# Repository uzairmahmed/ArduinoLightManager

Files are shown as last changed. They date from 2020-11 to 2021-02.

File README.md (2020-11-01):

# Google Home Lightstrip Controller
**Make your own smart LED Strips using Google Actions, Firebase Functions, Arduino, and the ESP8266 WiFi chip.**

*This guide is based off [shivasiddarth's](https://github.com/shivasiddharth) [YouTube Tutorial](https://www.youtube.com/watch?v=e1C5WIfZ89s&t=1096s)*

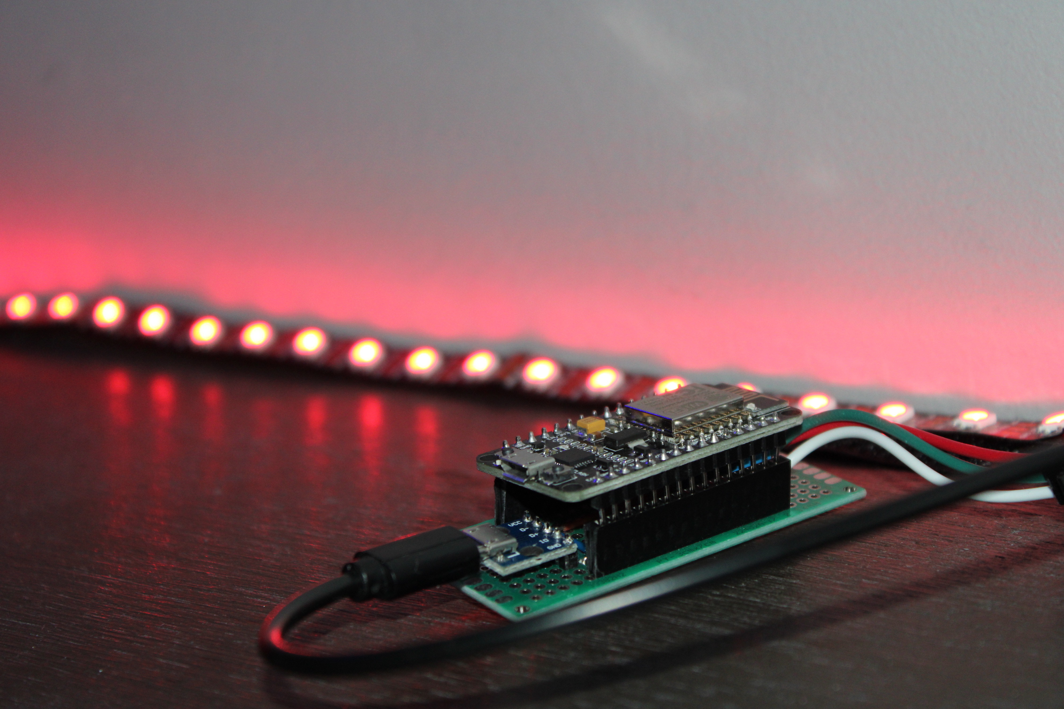
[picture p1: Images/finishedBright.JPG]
finishedController

---

## Google Actions Setup

1. Go to [Google Actions Console](console.actions.google.com)
2. Create a Project
3. Select `Smart Home`
4. Choose a name for the Action
5. Go to `Actions` and add the following fullfillment URL
    - `https://us-central1-PROJECT_ID.cloudfunctions.net/smarthome`
6. Go to `Account Linking` and add a Client ID and Secret
    - ID: `ABC123`
    - Secret `DEF456`
    - `https://us-central1-PROJECT_ID.cloudfunctions.net/fakeauth`
    - `https://us-central1-PROJECT_ID.cloudfunctions.net/faketoken`
7. Click Next
8. Go to Cloud Console and enable the `HomeGraph API` in `APIs and Services`
9. Add Credentials
    - Select `Service Account` and add the `Service Account Token Creator` role.
    - Create a JSON Key

---

## Firebase Setup

### Firebase Directory Setup

1. Clone this repository
2. Save the JSON key file from the previous step to `./Firebase/arduino-nodemcu-control/functions/smart-home-key.json`
3. Download [NodeJS](https://nodejs.org/en/)
4. Open a Powershell Terminal with administrator privileges
5. `cd` into `Firebase\arduino-nodemcu-control\functions`
6. `Set-ExecutionPolicy RemoteSigned` to enable scripts
7. `npm install -g firebase-tools` to install firebase
8. `firebase login`
9. `firebase use PROJECT_ID`
10. `npm i`
11. Go to [Firebase](console.firebase.google.com)
12. Click `Database > Create Database > Enable`, and copy the URL given
13. Click `Settings > Users and permissions > Service Accounts > Database secrets`  and copy the secret given

### Smart Devices Setup

1. For each device you intend to use, add an entry to the devices array inside `Firebase\arduino-nodemcu-control\functions\devices.json`
    - Use the template given in `Firebase\arduino-nodemcu-control\functions\device_template.json` for your entry
2. Customize your device further by referencing to the [Google Smarthome Docs](https://developers.google.com/assistant/smarthome/guides)

### Firebase Deployment

1. In a terminal, `cd` into `Firebase\arduino-nodemcu-control\functions`
2. `firebase deploy`
3. Go to the link specified.
4. Click `Database > Create Database > Enable`, and note down the URL given
5. Click `Realtime Database`
6. Click `Settings > Users and permissions > Service Accounts > Database secrets` and note down the secret given
7. Save your URL and Secret in a file, **you will need it later**.

---

## Hardware Setup

soldering

**Note:** The steps outlined above work for any type of device/hardware (lights, fans, motors, etc). The steps below are specifically to control LightStrips with Cloud Functions

### Circuit Building

#### **Components Needed**

- **1x** NodeMCU ESP8266 Development Board
- **1x** WS2812 LED Strip
- **1x** MicroUSB PinBoard (Female)
- **1x** 3-Pin Screw Terminal
- **2x** 15-Pin Headers
- **1x** 5-Pin Headers
- **5x** Jumper Cables
- **1x** 10x24-Hole Perfboard
- **1x** Micro USB Cable
- **1x** USB Power Supply

#### **Power Requirements**

The ESP8266 board operates at 3.3V, however the WS2812 operates at 5V. Additionally, the maximum current that can be drawn from each GPIO pin is 12mA. For this reason we need to power the board independently from the lightstrip, and with a larger power supply.

To choose an adequate power supply, we need to calculate the maximum current drawn from the arduino and the lights.

ESP8266 Board Max Current Draw: 400mA

WS2812 Strip Max Current Draw (all pixels are bright white): 3.6A

- Each LED draws a maximum of 60mA (Red, Green, Blue)
- 60 LED strip = 3.6 Amps required.

Therefore we need a 5V / 4A Power Supply.

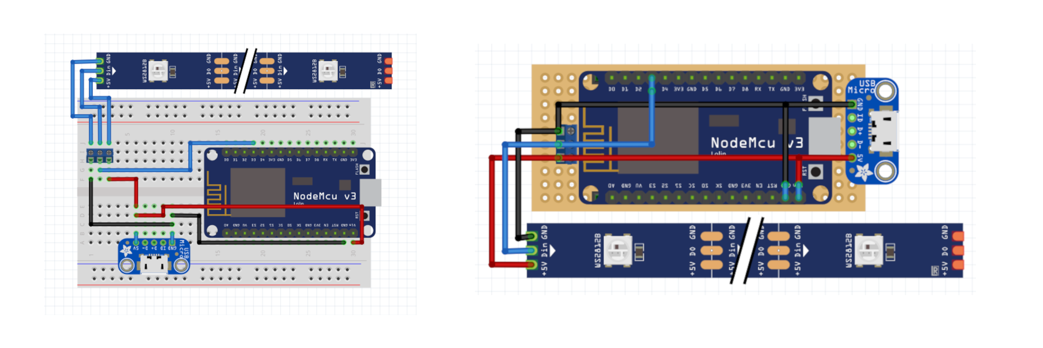
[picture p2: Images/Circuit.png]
Circuit


#### **Breadboard Testing**

1. Open `Wiring\Breadboard_Wiring.png`, and create the circuit shown.
2. To test the circuit, open `Arduino\OfflineLightManager\OfflineLightManager.ino` in Arduino.
3. If you have not already, setup your ESP8266 Board to work with Arduino IDE, Steps shown below in `Setup Arduino/NodeMCU Setup with Arduino IDE`.
4. Go to `Tools > Library Manager` and get
    - `FastLED` by `Daniel Garcia`
5. Connect the circuit to your computer using the microUSB port **on the ESP8266 board**
Click Upload
6. Confirm that the light strip turns on.
7. Reconnect the ciruit to your computer, but this time, use the microUSB port **on the external pinboard**
8. Confirm that the light strip turns on (but brighter).

#### **Perfboard Testing**

1. Open `Wiring\Perfboard_Wiring.png`, and solder the circuit shown.
2. Repeat steps 5-8 from the previous section to confirm your circuit board works.

### Arduino Setup

#### Configure NodeMCU with Arduino IDE

1. Open Arduino
2. Go to `File > Preferences`, under `Additional Boards Manager URLS` paste the following URL: `http://arduino.esp8266.com/stable/package_esp8266com_index.json`
3. Go to `Tools > Board > Boards Manager` and get `esp8266` by ESP8266 Community
4. Go to `Tools > Board` and select `NodeMCU 1.0 (ESP-12E)`

#### Upload LightManager Code

1. Download the git repository at [FirebaseExtended/firebase-arduino](https://github.com/FirebaseExtended/firebase-arduino)
2. Open `Arduino\LightManager\LightManager.ino` in Arduino.
3. Go to `Sketch > Include Library > Add ZIP Library`
4. Go to `Tools > Library Manager` and get

    - `ArduinoJSON` **v5.13** by `Benoit Blanchon`,
    - `WiFiManager` by `Tzapu, Tablatronix`,
    - `Adafruit_Neopixel` by `Adafruit`

5. Make the following changes to the code:
    - Replace `FIREBASE_URL` with the Firebase URL **saved earlier**.
    - Replace `FIREBASE_KEY` with the Firebase Secret **saved earlier**.
    - For each device you make:
        - Edit `LED_Count` variable to match the number of LEDs in your strip.
        - Edit `STRMDEVID` variable to match the ID of the device you created in `Firebase\arduino-nodemcu-control\functions\devices.json`.

6. Verify your code
7. Upload your code
8. Connect to the WiFi Network created by your ESP8266
9. Click `Configure Wifi` and connect to your home WiFi address (2.4GHz only)

---

## Google Home Setup

### Setup

1. Open your [Google Actions](console.actions.google.com) project
2. Go to `Google Actions Console > Test`
3. Invoke a test in the simulator, you will get an error, and then the Action will activate.
4. Open the Google Home app on a mobile device.
5. Go to `'+' > Set up Device > Have something already setup? > '[Test] Device Name'`
6. Add the [Test] Devices to a room and test the lights.
7. Refer to `Debugging` Below if something isn't working correctly.
8. **Congratulations! You've made your own smart Light Strips!**

Finished

---

---

## Debugging

If your lights aren't working properly, follow these steps to find the root of the issue.

1. Click the reset button on your ESP8266 Board (**this solves most issues**)
2. Firebase Debugging
    - Go to [Firebase Console](console.firebase.google.com) and open Realtime Database.
    - Change the color of your lights and make sure the values are changing in the database. 
        - If the database is unresponsive:
            - Confirm that Google Actions is setup properly with Firebase
            - Clear the Database and try changing colors again
            - Redeploy your Firebase Functions
        - If the database changes values properly, go to `External USB Debugging`.
3. External USB Debugging
    - Disconnect your circuit from the light strip and connect it to your computer using the microUSB port **on the ESP8266 board**.
    - Change the color of your lights and check if the lights change colors properly.
        - If they change properly, your external microUSB wiring isn't properly connected.
        - If they dont change, go to `Arduino WiFi Debugging`
4. Arduino WiFi Debugging
    - With your circuit connected to your computer, open Arduino,
    - Go to `Tools > Serial Monitor`.
    - If the serial monitor is sending `Streaming Error` indefinitely, check that your WiFi works properly.
    - OR If the serial monitor is sending instructions to connect to a WiFi network connect to the WiFi Network created by your ESP8266 and reconfigure your board.
    - OR Change the color of your lights and confirm that the serial monitor sends `patch` with the function you just activated.
        - If nothing shows up, confirm that Firebase is setup properly with Arduino
        - If the right output shows up, go to `Arduino Offline Debugging`
    - If none of the above worked/applied to you, go to `Arduino Offline Debugging`
5. Arduino Offline Debugging
    - Open `Arduino\OfflineLightManager\OfflineLightManager.ino` in Arduino.
    - If you don't have it already, go to `Tools > Library Manager` and get `FastLED` by `Daniel Garcia`
    - Upload the code and make sure that the LED strip turns on.
        - If the LED strip doesn't turn on, check your wiring, and make sure there are no short circuits anywhere.
        - If the LED strip does turn on properly, **something is wrong with your Google Actions / Firebase / LightController.ino setup**

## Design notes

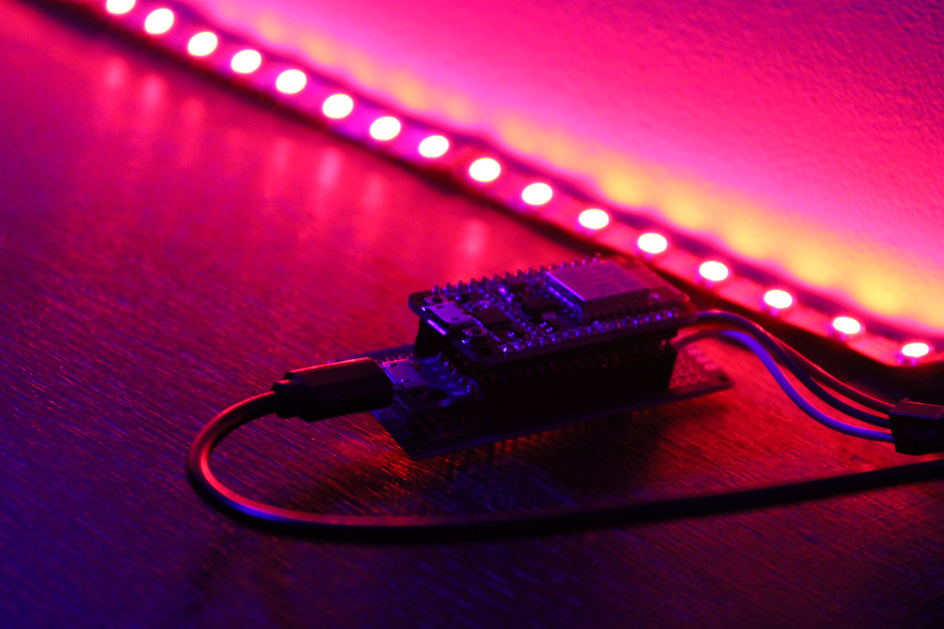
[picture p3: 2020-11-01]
Images/FinishedPurple.JPG

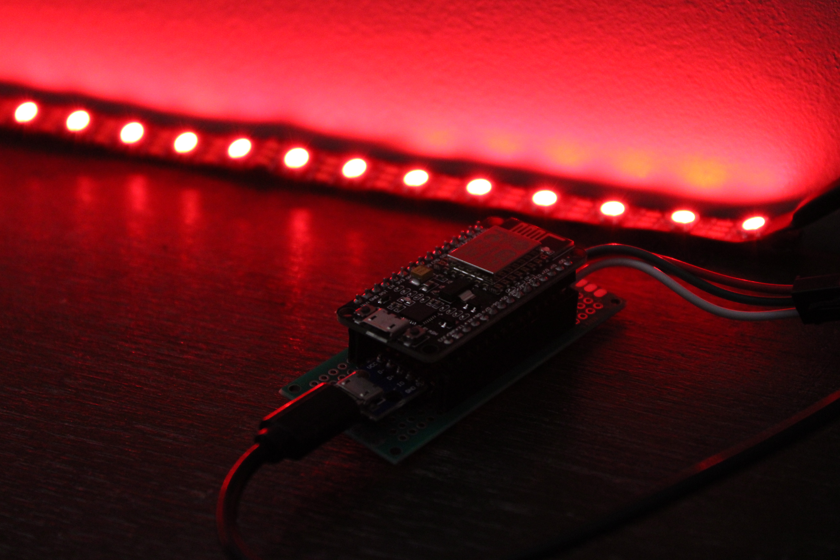
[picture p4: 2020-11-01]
Images/finishedRed.JPG

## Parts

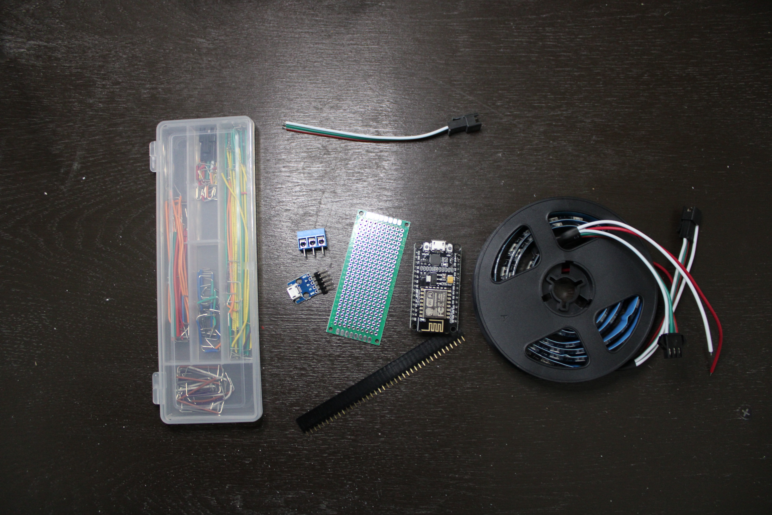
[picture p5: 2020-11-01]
Images/Parts.JPG

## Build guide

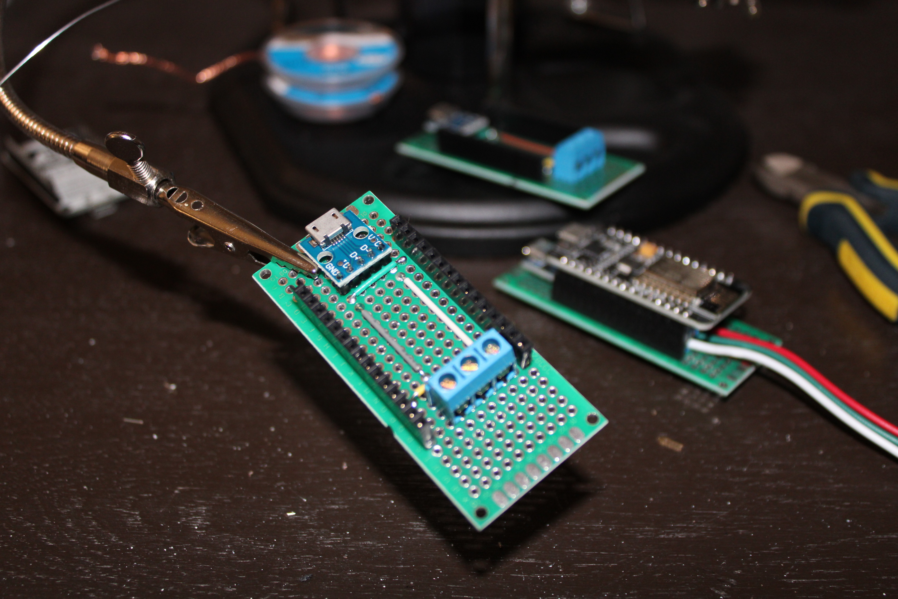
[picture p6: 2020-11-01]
Images/Soldered.JPG

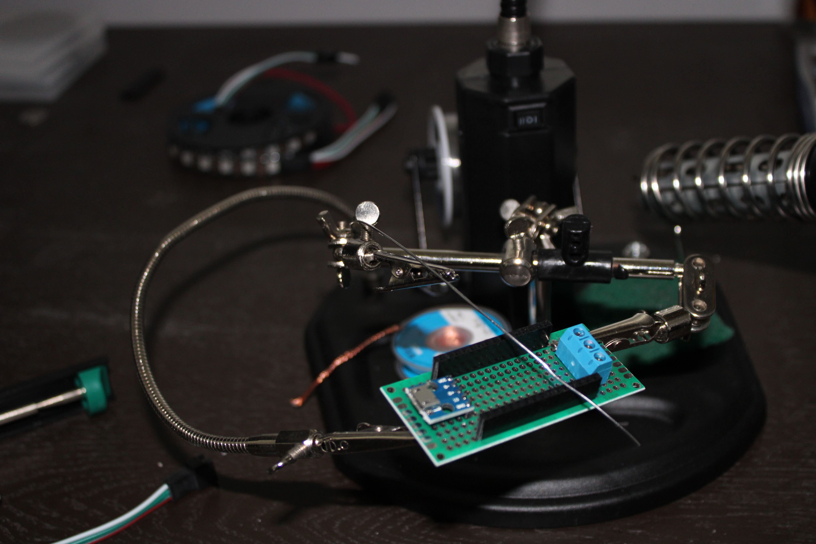
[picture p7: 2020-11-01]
Images/Soldering2.JPG

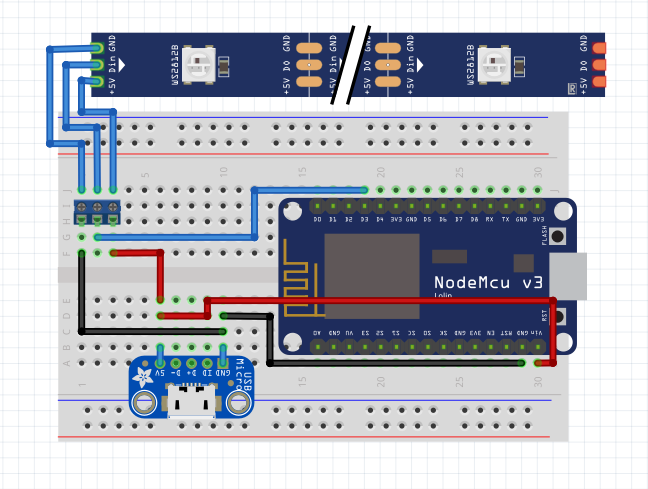
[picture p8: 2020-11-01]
Wiring/Breadboard_Wiring.png

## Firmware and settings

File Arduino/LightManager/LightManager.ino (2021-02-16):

//************************Written by Sid for Sid's E Classroom*****************************
//*************************https://github.com/shivasiddharth*******************************
//*************************Do not modify or remove this part******************************* 
//************If you are modifying or re-using the code, credit the the author*************

//********************************Modified by Uzair Ahmed**********************************
//***************************https://github.com/uzairmahmed********************************


#include <FirebaseArduino.h>
#include <ESP8266WiFi.h>
#include <DNSServer.h>
#include <ESP8266WebServer.h>
#include <WiFiManager.h>
#include <Adafruit_NeoPixel.h>
#include <EEPROM.h>

// Light Strip Data Pin
#define LED_PIN D3

// How many NeoPixels are attached to the Arduino?
#define LED_COUNT 60

// Declare NeoPixel strip object:
Adafruit_NeoPixel strip(LED_COUNT, LED_PIN, NEO_GRB + NEO_KHZ800);
// Argument 1 = Number of pixels in NeoPixel strip
// Argument 2 = Arduino pin number (most are valid)
// Argument 3 = Pixel type flags, add together as needed:
//   NEO_KHZ800  800 KHz bitstream (most NeoPixel products w/WS2812 LEDs)
//   NEO_KHZ400  400 KHz (classic 'v1' (not v2) FLORA pixels, WS2811 drivers)
//   NEO_GRB     Pixels are wired for GRB bitstream (most NeoPixel products)
//   NEO_RGB     Pixels are wired for RGB bitstream (v1 FLORA pixels, not v2)
//   NEO_RGBW    Pixels are wired for RGBW bitstream (NeoPixel RGBW products)

//EEPROM address definition
#define Start_Address 0
#define Bri_Address Start_Address + sizeof(int)
#define Clr_Address Bri_Address + sizeof(int)

//Firebase Database URL and KEY
// FIREBASE_DATABASE_URL "projectname.firebaseio.com"
#define FIREBASE_DATABASE_URL "uzairmahmeddotcom.firebaseio.com"
#define FIREBASE_KEY "7dMJuNJ5V17xTrgaz7NeF4nOL4VkzGj4Q4PRxu8O"

//Set the ID to the device id used in the index.json file
static const String STRMDEVID =  "2";

//Temperature in K
int Temperature[111] = {1000, 1100, 1200, 1300, 1400, 1500, 1600, 1700, 1800, 1900, 2000, 2100, 2200, 2300, 2400, 2500, 2600, 2700, 2800, 2900, 3000, 3100, 3200, 3300, 3400, 3500, 3600, 3700, 3800, 3900, 4000, 4100, 4200, 4300, 4400, 4500, 4600, 4700, 4800, 4900, 5000, 5100, 5200, 5300, 5400, 5500, 5600, 5700, 5800, 5900, 6000, 6100, 6200, 6300, 6400, 6500, 6600, 6700, 6800, 6900, 7000, 7100, 7200, 7300, 7400, 7500, 7600, 7700, 7800, 7900, 8000, 8100, 8200, 8300, 8400, 8500, 8600, 8700, 8800, 8900, 9000, 9100, 9200, 9300, 9400, 9500, 9600, 9700, 9800, 9900, 10000, 10100, 10200, 10300, 10400, 10500, 10600, 10700, 10800, 10900, 11000, 11100, 11200, 11300, 11400, 11500, 11600, 11700, 11800, 11900, 12000};
//Correspodning Hexcolor
unsigned long Hexcolor[111] = {0xFF3800, 0xFF4700, 0xFF5300, 0xFF5D00, 0xFF6500, 0xFF6D00, 0xFF7300, 0xFF7900, 0xFF7E00, 0xFF8300, 0xFF8A12, 0xFF8E21, 0xFF932C, 0xFF9836, 0xFF9D3F, 0xFFA148, 0xFFA54F, 0xFFA957, 0xFFAD5E, 0xFFB165, 0xFFB46B, 0xFFB872, 0xFFBB78, 0xFFBE7E, 0xFFC184, 0xFFC489, 0xFFC78F, 0xFFC994, 0xFFCC99, 0xFFCE9F, 0xFFD1A3, 0xFFD3A8, 0xFFD5AD, 0xFFD7B1, 0xFFD9B6, 0xFFDBBA, 0xFFDDBE, 0xFFDFC2, 0xFFE1C6, 0xFFE3CA, 0xFFE4CE, 0xFFE6D2, 0xFFE8D5, 0xFFE9D9, 0xFFEBDC, 0xFFECE0, 0xFFEEE3, 0xFFEFE6, 0xFFF0E9, 0xFFF2EC, 0xFFF3EF, 0xFFF4F2, 0xFFF5F5, 0xFFF6F7, 0xFFF8FB, 0xFFF9FD, 0xFEF9FF, 0xFCF7FF, 0xF9F6FF, 0xF7F5FF, 0xF5F3FF, 0xF3F2FF, 0xF0F1FF, 0xEFF0FF, 0xEDEFFF, 0xEBEEFF, 0xE9EDFF, 0xE7ECFF, 0xE6EBFF, 0xE4EAFF, 0xE3E9FF, 0xE1E8FF, 0xE0E7FF, 0xDEE6FF, 0xDDE6FF, 0xDCE5FF, 0xDAE5FF, 0xD9E3FF, 0xD8E3FF, 0xD7E2FF, 0xD6E1FF, 0xD4E1FF, 0xD3E0FF, 0xD2DFFF, 0xD1DFFF, 0xD0DEFF, 0xCFDDFF, 0xCFDDFF, 0xCEDCFF, 0xCDDCFF, 0xCFDAFF, 0xCFDAFF, 0xCED9FF, 0xCDD9FF, 0xCCD8F, 0xCCD8FF, 0xCBD7F, 0xCAD7F, 0xCAD6FF, 0xC9D6FF, 0xC8D5FF, 0xC7D4FF, 0xC6D4FF, 0xC6D4FF, 0xC5D3FF, 0xC5D3FF, 0xC5D2FF, 0xC4D2FF, 0xC3D2FF, 0xC3D1FF};

//Variables for brightness and color
int bri;
int clr;

//GAMER VARIABLE
bool rgbmode = false;

struct firebaseEvent{ 
  String path, eventType; 
}; 

typedef struct firebaseEvent Struct; 


void setup() {
  //Pull Data from previous setup
  Serial.begin(115200);
  EEPROM.begin(256);
  EEPROM.get(Bri_Address, bri);
  EEPROM.get(Clr_Address, clr);

  //Neopixel Initialization
  strip.begin();
  showLastLightSetup(bri, clr);

  //WiFi Manager
  WiFiManager wifiManager;
  wifiManager.autoConnect();
  Serial.println("Connected..");

  //Firebase Declaration
  Firebase.begin(FIREBASE_DATABASE_URL, FIREBASE_KEY);
  Firebase.stream(STRMDEVID);
}

void loop() {
  //Check Firebase connection
  if (Firebase.failed()) {
    Serial.println("Streaming Error");
    Serial.println(Firebase.error());
  }

  while(rgbmode == true){
    Serial.println("GAMER COLOR");
    rainbowCycle(20);
    FirebaseObject event = Firebase.readEvent();
    
    String path = FirebaseListener(event).eventType; 
    if (path == "patch"){
      rgbmode = false;
      Serial.println("Breaking out of Cycler");
      showLastLightSetup(bri, clr);
      break;
    }
  }
  
  if (Firebase.available()) {
    FirebaseObject event = Firebase.readEvent();
    Struct fbl = FirebaseListener(event);
    String path = fbl.path;
    String eventType = fbl.eventType; 

    if (eventType == "patch" || eventType == "put") {
      //If brightness is changed
      if (path == "/Brightness") {
        int bright = Firebase.getInt("/" + STRMDEVID + "/Brightness/brightness");
        Serial.println(bright);
        strip.setBrightness(bright);
        strip.show();
        bri = bright*2.5;
        EEPROM.put(Bri_Address, bri);
        EEPROM.commit();
        EEPROM.end();
        Serial.println(String(bri) + " BRIGHTNESS");
      }
      //If light is turned on or off
      else if (path == "/OnOff") {
        bool lightstatus = Firebase.getBool("/" + STRMDEVID + "/OnOff/on");
        if (lightstatus == 0) {
          strip.fill();
          strip.show();
        } else if (lightstatus == 1) {
          EEPROM.get(Clr_Address, clr);
          EEPROM.get(Bri_Address, bri);
          strip.fill(clr);
          strip.setBrightness(bri);
          strip.show();
        }
        Serial.println(String(lightstatus) + " STATUS");
      }
      else if (path == "/ColorSetting") {
        //If color is changed
        String colorname = Firebase.getString("/" + STRMDEVID + "/ColorSetting/color/name");
        Serial.println(colorname);
        String colors = event.getJsonVariant("data");
        //if the color is a temperature of white
        if (colors.indexOf("temperature") != -1) {
          int colortemp = Firebase.getInt("/" + STRMDEVID + "/ColorSetting/color/temperature");
          Serial.println(colortemp);
          Serial.println(Temperature[55]);
          if (colortemp == Temperature[55]){
            Serial.println("found GAMER COLOR");
            rgbmode = true;
          } else{
            rgbmode = false;
            for (int i = 1; i <= 111; i++) {
              if (colortemp == Temperature[i]) {
                int colorhex = Hexcolor[i];
                clr = colorhex;
                colorFade(clr);
                EEPROM.put(Clr_Address, clr);
                EEPROM.commit();
                EEPROM.end();
                break;
              }
            }
            Serial.println(String(clr) + " TEMPERATURE");
          }
        //if the color is a real color
        } else if (colors.indexOf("spectrumRGB") != -1) {
          rgbmode = false;
          int colordec = Firebase.getInt("/" + STRMDEVID + "/ColorSetting/color/spectrumRGB");
          clr = colordec;
          colorFade(clr);
          EEPROM.put(Clr_Address, clr);
          EEPROM.commit();
          EEPROM.end();
          Serial.println(String(clr) + " COLOR");
        }
      }
    }
  }
}

void showLastLightSetup(int bri, int clr){
  strip.fill(clr);
  strip.setBrightness(bri);
  strip.show();
  Serial.println("Current values: "+String(bri)+" , "+String(clr));
}

Struct FirebaseListener(FirebaseObject event){ 
  String eventType = event.getString("type");
  Serial.println(eventType);
  String path = event.getString("path");
  Serial.println(path);

  Struct s;
  s.path = path;
  s.eventType = eventType;
  return s;
}

// code to change fade between two colors
void colorFade(int c) {
  uint8_t b = c % 256;
  uint8_t g = ((c-b)/256) % 256;
  uint8_t r = ((c-b)/pow(256,2)) - r/256;
      uint8_t curr_r, curr_g, curr_b;
      uint32_t curr_col = strip.getPixelColor(0); // get the current colour
      curr_b = curr_col & 0xFF; 
      curr_g = (curr_col >> 8) & 0xFF; 
      curr_r = (curr_col >> 16) & 0xFF;  // separate into RGB components

      while ((curr_r != r) || (curr_g != g) || (curr_b != b)){  // while the curr color is not yet the target color
        if (curr_r < r) curr_r++; else if (curr_r > r) curr_r--;  // increment or decrement the old color values
        if (curr_g < g) curr_g++; else if (curr_g > g) curr_g--;
        if (curr_b < b) curr_b++; else if (curr_b > b) curr_b--;
        uint32_t color = (curr_r<<16) + (curr_g<<8) + (curr_b);
        strip.fill(color);  // set the color
        strip.show();
        delay(1);  // add a delay if its too fast
  }
}

void rainbowCycle(int SpeedDelay) {
  byte *c;
  uint16_t i, j;
  for(j=0; j<256; j++) { // 5 cycles of all colors on wheel   
    for(i=0; i< LED_COUNT; i++) {
      c=Wheel(((i * 256 / LED_COUNT) + j) & 255);
      strip.setPixelColor(i, *c, *(c+1), *(c+2));
    }
    strip.show();
    delay(SpeedDelay);
  }
}

byte * Wheel(byte WheelPos) {
  static byte c[3];
 
  if(WheelPos < 85) {
   c[0]=WheelPos * 3;
   c[1]=255 - WheelPos * 3;
   c[2]=0;
  } else if(WheelPos < 170) {
   WheelPos -= 85;
   c[0]=255 - WheelPos * 3;
   c[1]=0;
   c[2]=WheelPos * 3;
  } else {
   WheelPos -= 170;
   c[0]=0;
   c[1]=WheelPos * 3;
   c[2]=255 - WheelPos * 3;
  }

  return c;
}

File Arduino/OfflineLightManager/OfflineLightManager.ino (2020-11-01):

#include <FastLED.h>

// Light Strip Data Pin
#define LED_PIN     8

// Information about the LED strip itself
#define NUM_LEDS    30
#define CHIPSET     WS2811
#define COLOR_ORDER GRB
#define BRIGHTNESS  200
#define FORWARD 0
#define FAST 5

CRGB leds[NUM_LEDS];

#define STOP_BUTTON_PIN 3
#define PREV_BUTTON_PIN 2
#define NEXT_BUTTON_PIN 1

boolean oldPrevState = HIGH;
boolean oldNextState = HIGH;

int mode= 1;    // Currently-active animation mode, 0-9

void setup() {
  pinMode(PREV_BUTTON_PIN, INPUT_PULLUP);
  pinMode(NEXT_BUTTON_PIN, INPUT_PULLUP);
  pinMode(STOP_BUTTON_PIN, INPUT_PULLUP);

  
  LEDS.addLeds<CHIPSET,LED_PIN,COLOR_ORDER>(leds,NUM_LEDS);
  LEDS.setBrightness(BRIGHTNESS);
  colorWipe(CRGB::Red,FORWARD,FAST);    // Black/off

  Serial.begin(9600);
}

void loop() {
  // Get current button state.
  boolean newPrevState = digitalRead(PREV_BUTTON_PIN);
  boolean newNextState = digitalRead(NEXT_BUTTON_PIN);
  boolean stopState = digitalRead(STOP_BUTTON_PIN);          
  int cycleNumber = 0;

  Serial.println(digitalRead(PREV_BUTTON_PIN));

  // Check if state changed from high to low (button press).
  if(((newPrevState == LOW) && (oldPrevState == HIGH)) || ((newNextState == LOW) && (oldNextState == HIGH))) {
      Serial.println("true");
    // Short delay to debounce button.
    delay(250);
    // Check if button is still low after debounce.
    newPrevState = digitalRead(PREV_BUTTON_PIN);
    newNextState = digitalRead(NEXT_BUTTON_PIN);

    if(newPrevState == LOW) {
      if(--mode < 0) mode = 7;
    }
    if(newNextState == LOW) {
      if(++mode > 7) mode = 0;
    }
    
    if((newPrevState == LOW) || (newNextState == LOW)) {      // Yes, still low
      switch(mode) {           // Start the new animation...
        case 0:
          colorWipe(CRGB::Black,FORWARD,FAST);    // Black/off
          break;
        case 1:
          colorWipe(CRGB::Red,FORWARD,FAST);    // Red
          break;
        case 3:
          colorWipe(CRGB::Blue,FORWARD,FAST);    // Blue
          break;
        case 4:
          colorWipe(CRGB::Green,FORWARD,FAST);    // Green
          break;
        case 5:
          colorWipe(CRGB::White,FORWARD,FAST);    // White
          break;
        case 6:
          colorWipe(CRGB::Teal,FORWARD,FAST);    // Teal
          break;
        case 7:
          colorWipe(CRGB::DeepPink,FORWARD,FAST);    // Pink  `
          break;
        case 2:
          while(mode == 2){
            rainbow(FAST);
            if((digitalRead(PREV_BUTTON_PIN) == LOW) 
                || (digitalRead(NEXT_BUTTON_PIN)==LOW)) break;
          }
          break;         
        }
      }
    }
  // Set the last-read button state to the old state.
  oldPrevState = newPrevState;
  oldNextState = newNextState;
}

void colorWipe(CRGB c, int speed, int direction){
  for(int i=0; i<NUM_LEDS; i++){
    if(direction == FORWARD){
      leds[i] = c;
    }
    else{
      leds[NUM_LEDS-1-i] = c;
    }
    FastLED.show();
    delay(speed);
  }
}

void rainbow(int speed){
  for(int j=0; j<256; j++){
    for(int i=0; i< NUM_LEDS; i++) {
      leds[i] = Wheel((i*1+j) & 255);
    }
    FastLED.show();
    delay(speed);
  }
}

void disolve(int simultaneous, int cycles, int speed){
  int value = 15;
  for(int j=0; j<simultaneous; j++){
    int idx = random(NUM_LEDS);
    leds[idx] = CRGB::Black;
    
    CRGB randomCol = randomColor();
    for(int i = 0; i < value; i++){
      leds[idx] = fadeTowardColor(leds[idx], randomCol, value);
      FastLED.show();
      delay(10);
    }
    
    for(int i = value; i > 0; i--){
      leds[idx] = fadeTowardColor(leds[idx], CRGB::Black, value);
      FastLED.show();
      delay(10);
    }
  }
}

void cylon(CRGB c, int width, int speed){
  // First slide the leds in one direction
  for(int i = 0; i <= NUM_LEDS-width; i++) {
    for(int j=0; j<width; j++){
      leds[i+j] = c;
    }

    FastLED.show();

    // now that we've shown the leds, reset to black for next loop
    for(int j=0; j<5; j++){
      leds[i+j] = CRGB::Black;
    }
    delay(speed);
  }

  // Now go in the other direction.  
  for(int i = NUM_LEDS-width; i >= 0; i--) {
    for(int j=0; j<width; j++){
      leds[i+j] = c;
    }
    FastLED.show();
    for(int j=0; j<width; j++){
      leds[i+j] = CRGB::Black;
    }

    delay(speed);
  }
}

// Input a value 0 to 255 to get a color value.
// The colours are a transition r - g - b - back to r.
CRGB Wheel(byte WheelPos) {
  if(WheelPos < 85) {
    return CRGB(WheelPos * 3, 255 - WheelPos * 3, 0);
  } 
  else if(WheelPos < 170) {
    WheelPos -= 85;
    return CRGB(255 - WheelPos * 3, 0, WheelPos * 3);
  } 
  else {
    WheelPos -= 170;
    return CRGB(0, WheelPos * 3, 255 - WheelPos * 3);
  }
}

CRGB fadeTowardColor( CRGB& cur, const CRGB& target, uint8_t amount)
{
  nblendU8TowardU8( cur.red,   target.red,   amount);
  nblendU8TowardU8( cur.green, target.green, amount);
  nblendU8TowardU8( cur.blue,  target.blue,  amount);
  return cur;
}

// Helper function that blends one uint8_t toward another by a given amount
void nblendU8TowardU8( uint8_t& cur, const uint8_t target, uint8_t amount)
{
  if( cur == target) return;
 
  if( cur < target ) {
    uint8_t delta = target - cur;
    delta = scale8_video( delta, amount);
    cur += delta;
  } else {
    uint8_t delta = cur - target;
    delta = scale8_video( delta, amount);
    cur -= delta;
  }
}


CRGB randomColor(){
  return Wheel(random(256)); 
}

void allColor(CRGB c){
  for(int i=0; i<NUM_LEDS; i++){
    leds[i] = c;
  }
  FastLED.show();
}

void allRandom(){
  for(int i=0; i<NUM_LEDS; i++){
    leds[i] = randomColor();
  }
  FastLED.show(); 
}

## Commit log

2020-05-19 Reset project
    switching to full IoT on NodeMCU
    [LightManager.ino]
2020-11-01 finished guide
    [Breadboard_Circuit.fzz, Perfboard_Circuit.fzz]
